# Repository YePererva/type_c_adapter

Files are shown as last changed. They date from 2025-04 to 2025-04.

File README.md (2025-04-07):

# [WIP] USB Type C Receptacle to USB 2.0 breakout board

A few breakout boards for USB Type C Receptacle to breadboard and flex ribbon cables.

## Purpose

Fix / upgrade some equipment that is still using previous generation of USB connectors

## Why?

1. Because most of found adapter boards are missing (or have only 1) pull-down 5K1 resistors, while 2 of those are required
2. I also want to have alternative option with EDS protection IC
3. I wanted to have extra opportunity to use 5-pin flat ribbon cable instead of loose wires

Additionally:

- use the size of SMD components that are still solderable manually (0805 Resistors)

## Details

This repository contains 2 kinds of breakout board:

- simple
- with ESD protection: utilizing USBLC6-2SC6 IC (same as used on STM32-Nucleo boards)

Both versions contain:
- 16-pin USB Type Receptacle
- 4-pin regular breadboard-friendly pin-header
- 2 x 5-pin soldering footprints for flat-ribbon cable with the same pitch as USB Micro connector
	- straight pin-out
	- mirrored pin-out

Solder to the footprint depending on the side, you'll install this adapter in your device. Silkscreen provides details regrading the pin-out.

## Visuals

| Variation | Top-view | Bottom view |
| :--- | :---: | :---: |
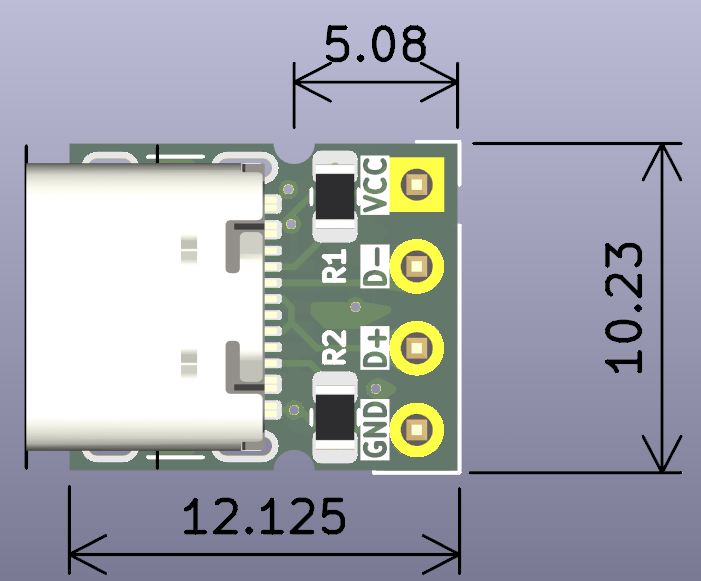
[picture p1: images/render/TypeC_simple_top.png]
Simple top view
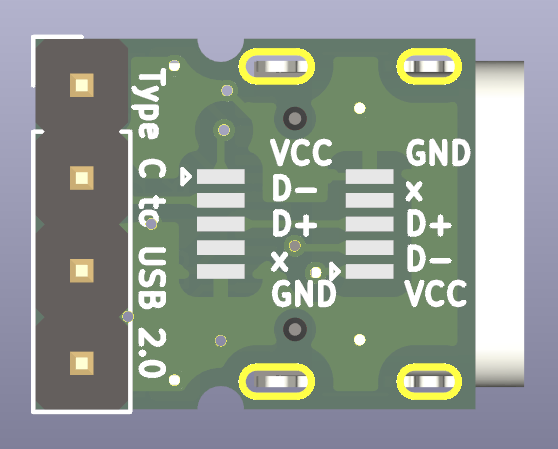
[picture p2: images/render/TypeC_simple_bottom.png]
Simple bottom view
| Simple |  |  |
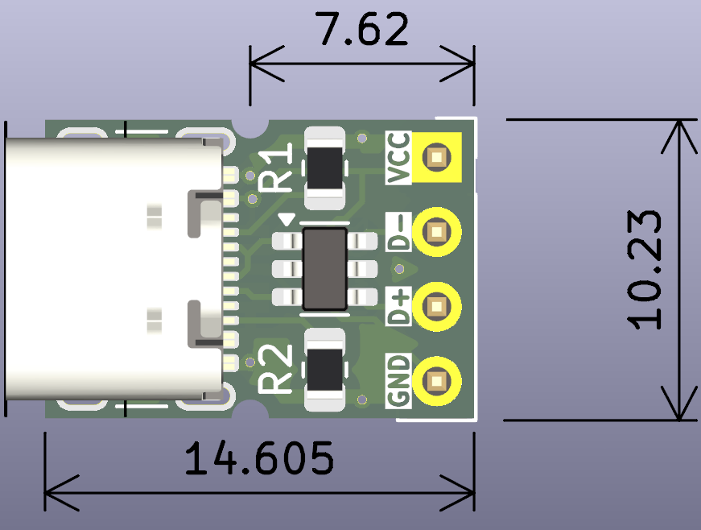
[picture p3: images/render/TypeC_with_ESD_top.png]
ESD top view
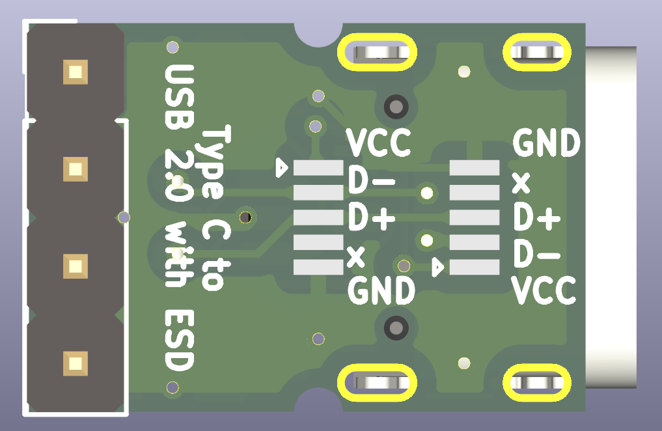
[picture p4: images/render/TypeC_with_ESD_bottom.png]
ESD bottom view
| With ESD |  |  |

## Remarks

There are a few tended vias used in these PCB, which is not ussually recomended. However, it seem to be the safest way of having some connections under the USB connector.  

## Thoughts on further

The only two things I would like to improove in these PCB are:

- to find pin-to-pin compatible USB Type C connector with water-proof housing
- having extra the PCB mounting bracket (like the availble with M2 screws) 
- modify the pin-headers to castelated holes

## Inspirations

There are a few similar solutions on market. Not all of them has even footprints for pull-down resistors, and none of them have footprints for flex flat cable.

### Regular breakout boards

Available from manufacturers as [Adafruit](https://www.adafruit.com/product/4090), [Sparkfun](https://www.sparkfun.com/sparkfun-usb-c-breakout.html), [Popolu](https://www.pololu.com/product/2585), etc.

Usually have access to all additional pins (`CC1`, `CC2`, etc.) which make them large. However these variations are breadboard friendly.

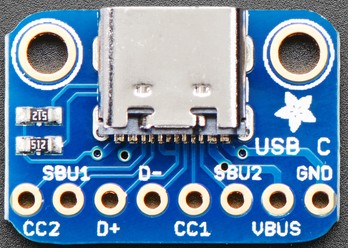
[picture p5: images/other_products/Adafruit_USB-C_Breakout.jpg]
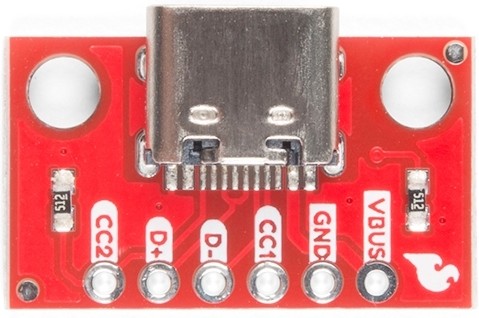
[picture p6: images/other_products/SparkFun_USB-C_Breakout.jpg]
|  |    |
| -- | -- |

### Simpistic breakout boards

Available from [Adafruit](https://www.adafruit.com/product/5180) and and some not so known brands. Usually very compact and might have the soldering place for breadboard pins.

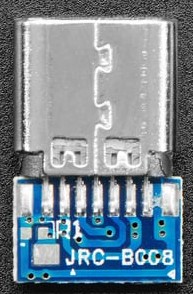
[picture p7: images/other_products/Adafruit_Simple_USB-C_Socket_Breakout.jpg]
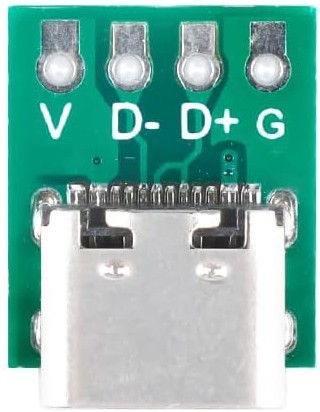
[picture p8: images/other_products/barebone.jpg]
|  |    |
| -- | -- |

### Other

[μC USB Type C Breakout Board](https://www.tindie.com/products/casualcoders/c-usb-type-c-breakout-board-5-pack/) by [Casual Coders](https://www.tindie.com/stores/casualcoders/) on Tindie.

Also, available on [GitHub](https://github.com/CasualCodersProjects/uC-Breakout)

It seem to be nice, but I don't need access to all 8 pins, it uses small size resistors and can't be used with breadboard.

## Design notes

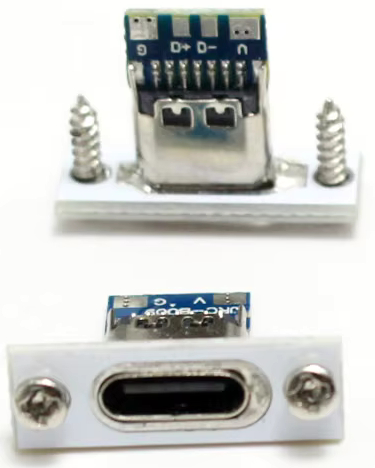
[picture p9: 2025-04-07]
images/other_products/with_mointing_plate.jpg

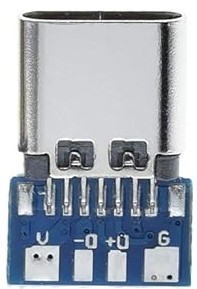
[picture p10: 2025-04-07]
images/other_products/barebone_2.jpg

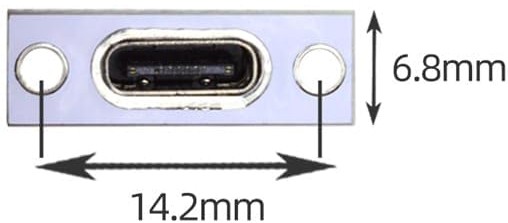
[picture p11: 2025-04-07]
references/bracket_drawings/51L6O6nt2OL._AC_SL1000_.jpg

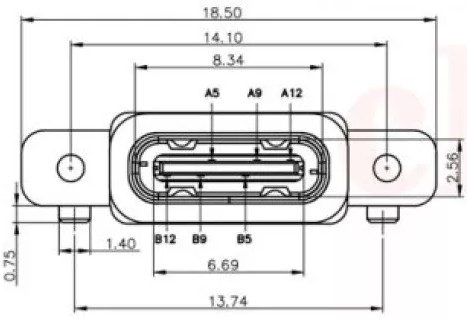
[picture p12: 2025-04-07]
references/bracket_drawings/PAN-USB-C-SL-DIM1-500x500.jpg

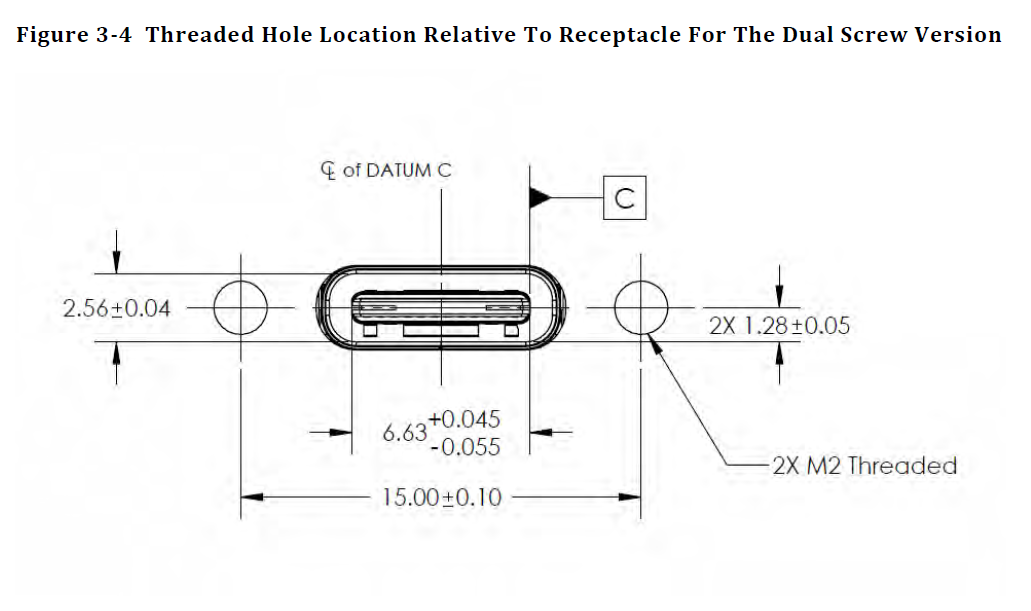
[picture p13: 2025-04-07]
references/bracket_drawings/bd75cf8a918120651273d0a94ace47d1c933943b.png

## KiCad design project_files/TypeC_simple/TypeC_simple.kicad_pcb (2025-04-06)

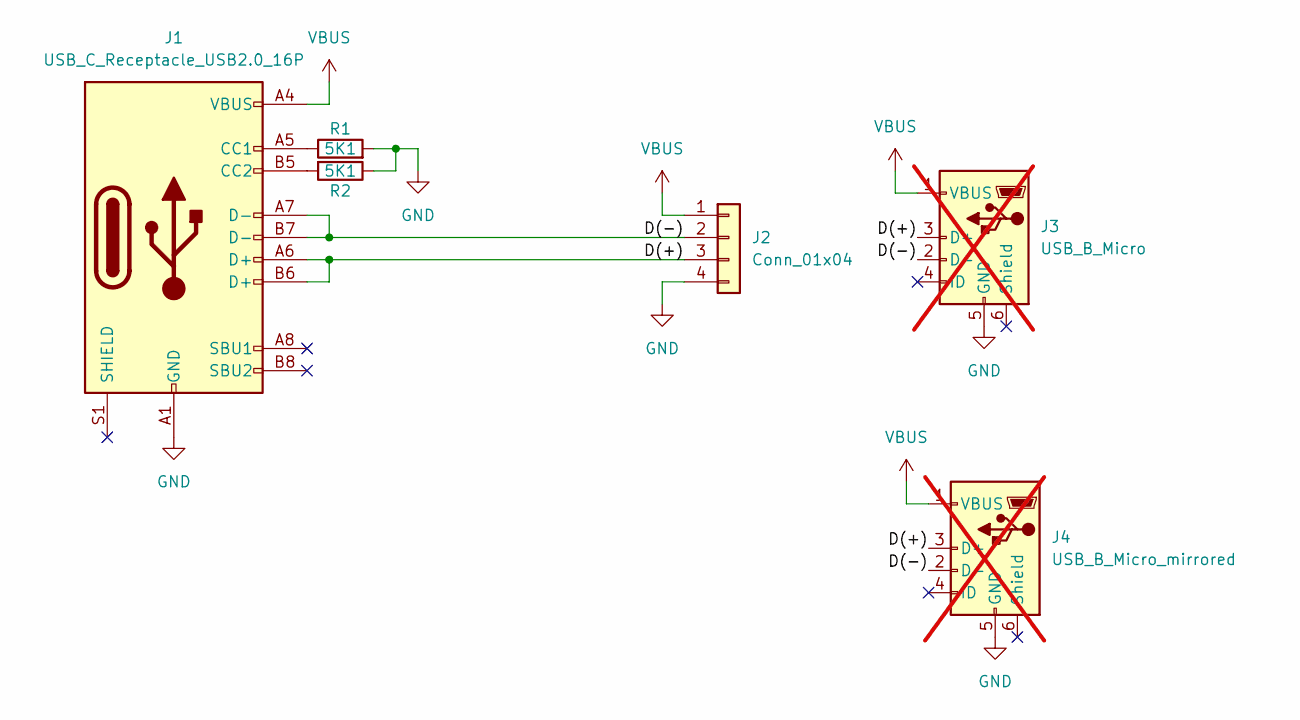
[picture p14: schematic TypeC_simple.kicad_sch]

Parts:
J1: USB_C_Receptacle_USB2.0_16P; USB_C_Receptacle_GCT_USB4105-xx-A_16P_TopMnt_Horizontal
J2: Conn_01x04; PinHeader_1x04_P2.54mm_Vertical
J3: USB_B_Micro; USB_Micro-B_Technik_TWP-4002D-H3; not fitted
J4: USB_B_Micro_mirrored; USB_Micro-B_Technik_TWP-4002D-H3; not fitted
R1, R2: 5K1; R_0805_2012Metric

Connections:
/D(+): J1.A6 (D+), J1.B6 (D+), J2.3, J3.3 (D+), J4.3 (D+)
/D(-): J1.A7 (D-), J1.B7 (D-), J2.2, J3.2 (D-), J4.2 (D-)
GND: J1.A1 (GND), J1.A12 (GND), J1.B1 (GND), J1.B12 (GND), J2.4, J3.5 (GND), J4.5 (GND), R1.2, R2.1
unnamed: J1.A5 (CC1), R1.1
unnamed: J1.B5 (CC2), R2.2
VBUS: J1.A4 (VBUS), J1.A9 (VBUS), J1.B4 (VBUS), J1.B9 (VBUS), J2.1, J3.1 (VBUS), J4.1 (VBUS)

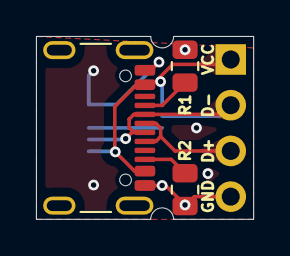
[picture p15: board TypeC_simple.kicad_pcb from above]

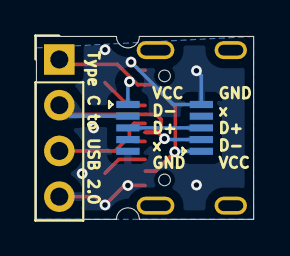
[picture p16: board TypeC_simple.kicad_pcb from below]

Board: 2 copper layers, 12.1 x 10.2 mm, 6 parts (3 on the bottom side), 6 nets.

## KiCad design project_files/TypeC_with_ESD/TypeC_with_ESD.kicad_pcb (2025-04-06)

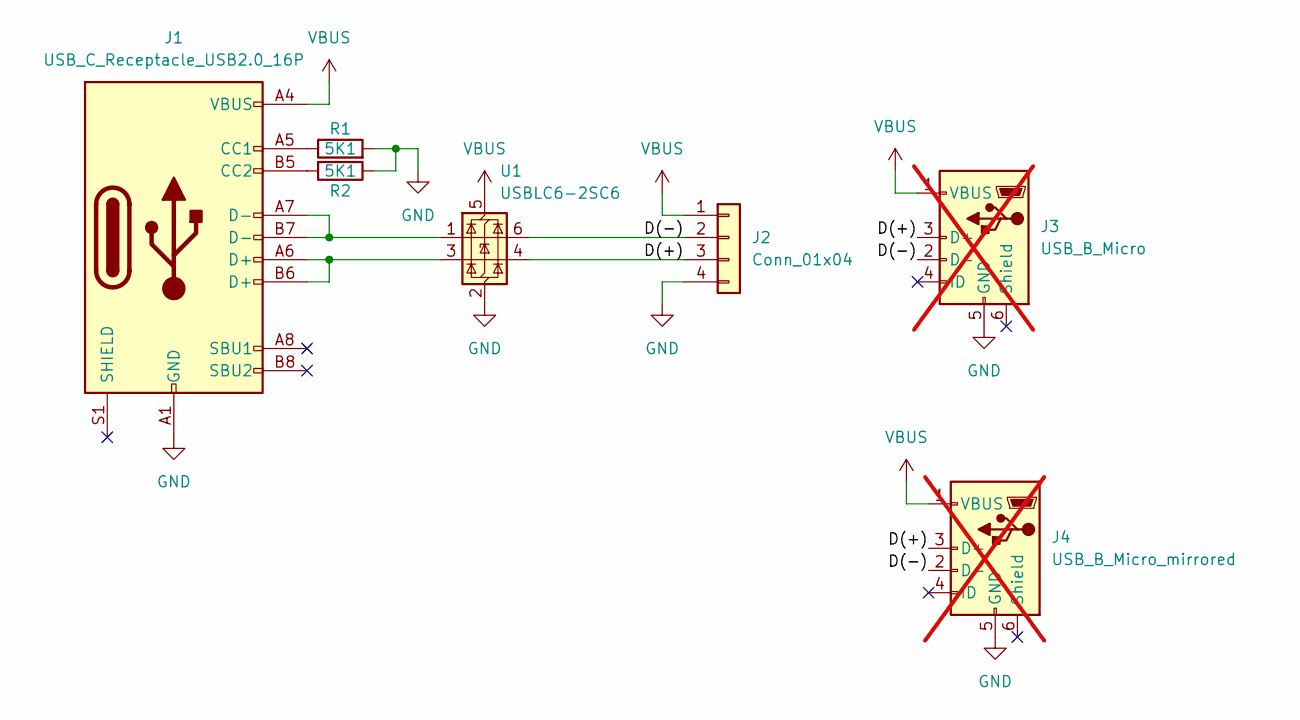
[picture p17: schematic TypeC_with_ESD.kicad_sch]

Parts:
J1: USB_C_Receptacle_USB2.0_16P; USB_C_Receptacle_GCT_USB4105-xx-A_16P_TopMnt_Horizontal
J2: Conn_01x04; PinHeader_1x04_P2.54mm_Vertical
J3: USB_B_Micro; USB_Micro-B_Technik_TWP-4002D-H3; not fitted
J4: USB_B_Micro_mirrored; USB_Micro-B_Technik_TWP-4002D-H3; not fitted
R1, R2: 5K1; R_0805_2012Metric
U1: USBLC6-2SC6; SOT-23-6

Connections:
/D(+): J2.3, J3.3 (D+), J4.3 (D+), U1.4 (I/O2)
/D(-): J2.2, J3.2 (D-), J4.2 (D-), U1.6 (I/O1)
GND: J1.A1 (GND), J1.A12 (GND), J1.B1 (GND), J1.B12 (GND), J2.4, J3.5 (GND), J4.5 (GND), R1.2, R2.1, U1.2 (GND)
unnamed: J1.A5 (CC1), R1.1
unnamed: J1.B5 (CC2), R2.2
unnamed: J1.A6 (D+), J1.B6 (D+), U1.3 (I/O2)
unnamed: J1.A7 (D-), J1.B7 (D-), U1.1 (I/O1)
VBUS: J1.A4 (VBUS), J1.A9 (VBUS), J1.B4 (VBUS), J1.B9 (VBUS), J2.1, J3.1 (VBUS), J4.1 (VBUS), U1.5 (VBUS)

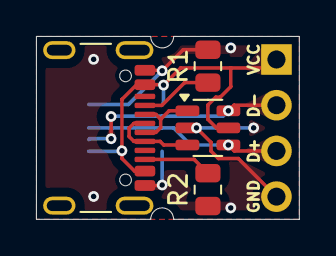
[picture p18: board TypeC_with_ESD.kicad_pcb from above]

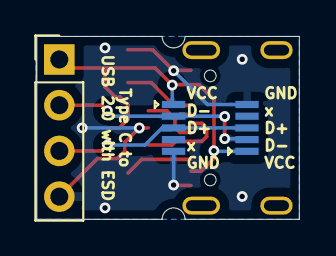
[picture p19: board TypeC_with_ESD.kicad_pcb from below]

Board: 2 copper layers, 14.6 x 10.2 mm, 7 parts (3 on the bottom side), 8 nets.
